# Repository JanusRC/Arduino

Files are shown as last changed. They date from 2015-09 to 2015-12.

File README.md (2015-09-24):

Janus Arduino Library
===

www.janus-rc.com

Janus Arduino repository for shield hardware and software references. 
The Janus Plugin Arduino Shield is fully compatible with the Arduino Uno and Leonardo currently.

This library should aid in getting a proof of concept with the Janus Plug in Modems done extremely 
quickly, allowing application development to focus on the bigger picture.

### Hardware
Arduino Shield and accessories - Designed in EAGLE 7.3.0

* `Plugin Shield v2.0`: Arduino Shield - Tested for the Uno/Leonardo
* `Eagle Library`: Janus Eagle Library

### Software
Janus software library for the Arduino platform, with example demos for standard M2M/IoT implementations.

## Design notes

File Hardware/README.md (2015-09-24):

Janus Arduino Library - Hardware
===

www.janus-rc.com

Janus Arduino hardware repository. Contains board designs for shields and accessories.

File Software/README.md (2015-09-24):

Janus Arduino Library - Software
===

www.janus-rc.com

Janus Arduino software repository. Contains backend library and demo code.

This library should aid in getting a proof of concept with the Janus Plug in Modems done extremely 
quickly, allowing application development to focus on the bigger picture.

These demos are for evaluations purposes only. Janus provides them as-is without any warranty or guarantees. 

### Janus Plugin Library
Arduino Shield library for use with the Janus Plugin Modem or Telit Modem.

* `Baudrate_Change`: Adjust the modem's baud rate.
* `Modem_Information`: Prints out the modem's information, including SIM serial and Network.
* `Modem_Terminal`: Cross connect the UART for quick evaluation and direct AT commands.
* `Modem_USBControl`: Turn the external USB on or off
* `SMS_Echo`: M2M Demo - Listens for incoming SMS, prints the information, and echoes back to the sender.
* `Socket_Dial`: M2M Demo - Dials out to a remote host, opens a serial bridge
* `Socket_Listen`: M2M Demo - Creates a listening host, once a client connects a serial bridge is open.

The Listener demo will create a completely open listener if you have an externally routable IP. Please be careful to shut this down
once testing is complete as you may find someone will connect to it and rack up your data usage. This is by default, but can be changed
in the demo by the user if needed with setupFirewall.

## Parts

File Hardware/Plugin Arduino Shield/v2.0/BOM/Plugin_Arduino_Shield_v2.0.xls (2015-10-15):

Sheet: Sheet1
Board Name | Plug in Module Arduino Shield
Item | Qty | Ref. Designator | Value | Part Number | Description | Package | Type | Side | Notes
0 | 6 | C1, C7, C8, C9, C10, C11 | 0.1uF | LMK105BJ104KV-F | CAP CER 0.1UF 10V 10% X5R 0402 | 402 | SMT | TOP
1 | 2 | C2, C3 | 10uF | JMK212BJ106KD-T | CAP CER 10UF 6.3V 10% X5R 0805 | 805 | SMT | TOP
2 | 2 | C4, C5 | .022uF | LMK105B7223KV-F | CAP CER 0.022UF 10V 10% X7R 0402 | 402 | SMT | TOP
3 | 1 | C6 | 100uF | GRM31CR60J107ME39K | CAP CER 100UF 6.3V 20% X5R 1206 | 1206 | SMT | TOP
4 | 1 | D1 | LED0603 | LG L29K-F2J1-24-Z | LED SMARTLED 570NM GREEN 0603 | 603 | SMT | TOP
5 | 1 | P5 | x | 10104110-0001LF | CONN RCPT STD MICRO USB TYPE B | MICRO USB SMT-RA | SMT | TOP
6 | 5 | Q1, Q2, Q3 | BJT-NPN | MMBT2222ALT1G | TRANS NPN 40V 0.6A SOT23 | SOT23 | SMT | TOP
7 | 1 | Q5 | MOSFET-P | IRLML6401TRPBF | MOSFET P-CH 12V 4.3A SOT-23 | SOT23 | SMT | TOP
8 | 2 | R1, R8 | 47k | ERJ-2RKF4702X | RES SMD 47K OHM 1% 1/10W 0402 | 402 | SMT | TOP
9 | 3 | R10, R11, R12 | 10k | ERJ-2RKF1002X | RES SMD 10K OHM 1% 1/10W 0402 | 402 | SMT | TOP
10 | 1 | R2 | 1.07k | ERJ-2RKF1071X | RES SMD 1.07K OHM 1% 1/10W 0402 | 402 | SMT | TOP
11 | 1 | R3 | 5.62k | ERJ-2RKF5621X | RES SMD 5.62K OHM 1% 1/10W 0402 | 402 | SMT | TOP
12 | 2 | R4, R5 | 2.2k | RC0402JR-072K2L | RES SMD 2.2K OHM 5% 1/16W 0402 | 402 | SMT | TOP
13 | 2 | R6, R7 | 4.7k | RC0402JR-074K7L | RES SMD 4.7K OHM 5% 1/16W 0402 | 402 | SMT | TOP
14 | 1 | R9 | 1.5k | RC0402JR-071K5L | RES SMD 1.5k OHM 5% 1/16W 0402 | 402 | SMT | TOP
15 | 1 | U1 | x | LMZ12002TZ-ADJ | IC BUCK SYNC ADJ 2A TO-PMOD-7 | TO-PMOD-7 | SMT | TOP
16 | 2 | U3, U4 | x | SN74LVC2T45DCT | IC BUS TRANSCVR 2BIT N-INV SM8 | 8-LSSOP | SMT | TOP
17 | 1 | P1 | x | M20-9720345 | 2x3 0.1” Header | 2x3 0.1” | Through Hole | TOP
18 | 1 | P2 | x | N/A | Wellshow SMA to GSC PCB R/A | RF SMA R/A 4 Pin | Through Hole | TOP
19 | 2 | P3, P4 | x | Arduino Header – 8 Pin | 8 Pin Long Lead Stacking Header | 1x8 0.1” | Through Hole | TOP
20 | 1 | P6 | x | Arduino Header – 6 Pin | 6 Pin Long Lead Stacking Header | 1x6 0.1” | Through Hole | TOP
21 | 1 | P7 | x | Arduino Header – 10 Pin | 10 Pin Long Lead Stacking Header | 1x10 0.1” | Through Hole | TOP
22 | 1 | P8 | x | SLW-124-01-G-S | 1x24 0.1” Samtec Low Profile Socket | 1x24 0.1” | Through Hole | TOP
23 | 1 | P9 | x | SLW-125-01-G-S | 1x25 0.1” Samtec Low Profile Socket | 1x25 0.1” | Through Hole | TOP
24 | 2 | S1, S2 | x | 1825027-5 | SWITCH TACTILE SPST-NO 0.05A 24V | 4 Pin THT | Through Hole | TOP
25 | 1 | U2 | x | HSPA910CF v1.0 | JANUS PLUG IN HSPA MODEM | x910 CF | Through Hole | TOP

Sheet: PuM_Arduino_Shield
Qty | Value | Device | Package | Parts | Description
1 | LED0603 |  | 603 | D1 | LEDs
5 | MOSFET-N |  | SOT23 | Q1, Q2, Q3, Q4, Q6 | IRLL014:
1 | MOSFET-P |  | SOT23 | Q5
2 | .022uF | C-0402 | 402 | C4, C5
2 | 0.1uF | C-0402 | 402 | C1, C7
1 | 1.07k | R-0402 | 402 | R2
1 | 1.5k | R-0402 | 402 | R9
5 | 100k | R-0402 | 402 | R1, R8, R10, R11, R12
1 | 100uF | C-1206 | 1206 | C6
2 | 10uF | C-0805 | 805 | C2, C3
2 | 2k | R-0402 | 402 | R4, R5
2 | 4.7k | R-0402 | 402 | R6, R7
1 | 5.62k | R-0402 | 402 | R3
1 | LMZ12002TZ-ADJ | TO-PMOD-7 | TO-PMOD-7 | U1
1 | RF_SMA | RF_SMA | RF SMA R/A 4 Pin | P2
2 | SWITCH-MOMENTARY | SWITCH-MOMENTARY | 4 Pin THT | S1, S2
1 | TERMINUS_X910CF | TERMINUS_X910CF | x910 CF | U2 | Terminus x910CF Plug in Module
1 | USB-MICROB | USB-MICROB | Micro USB SMT | P5 | Micro B USB Connector

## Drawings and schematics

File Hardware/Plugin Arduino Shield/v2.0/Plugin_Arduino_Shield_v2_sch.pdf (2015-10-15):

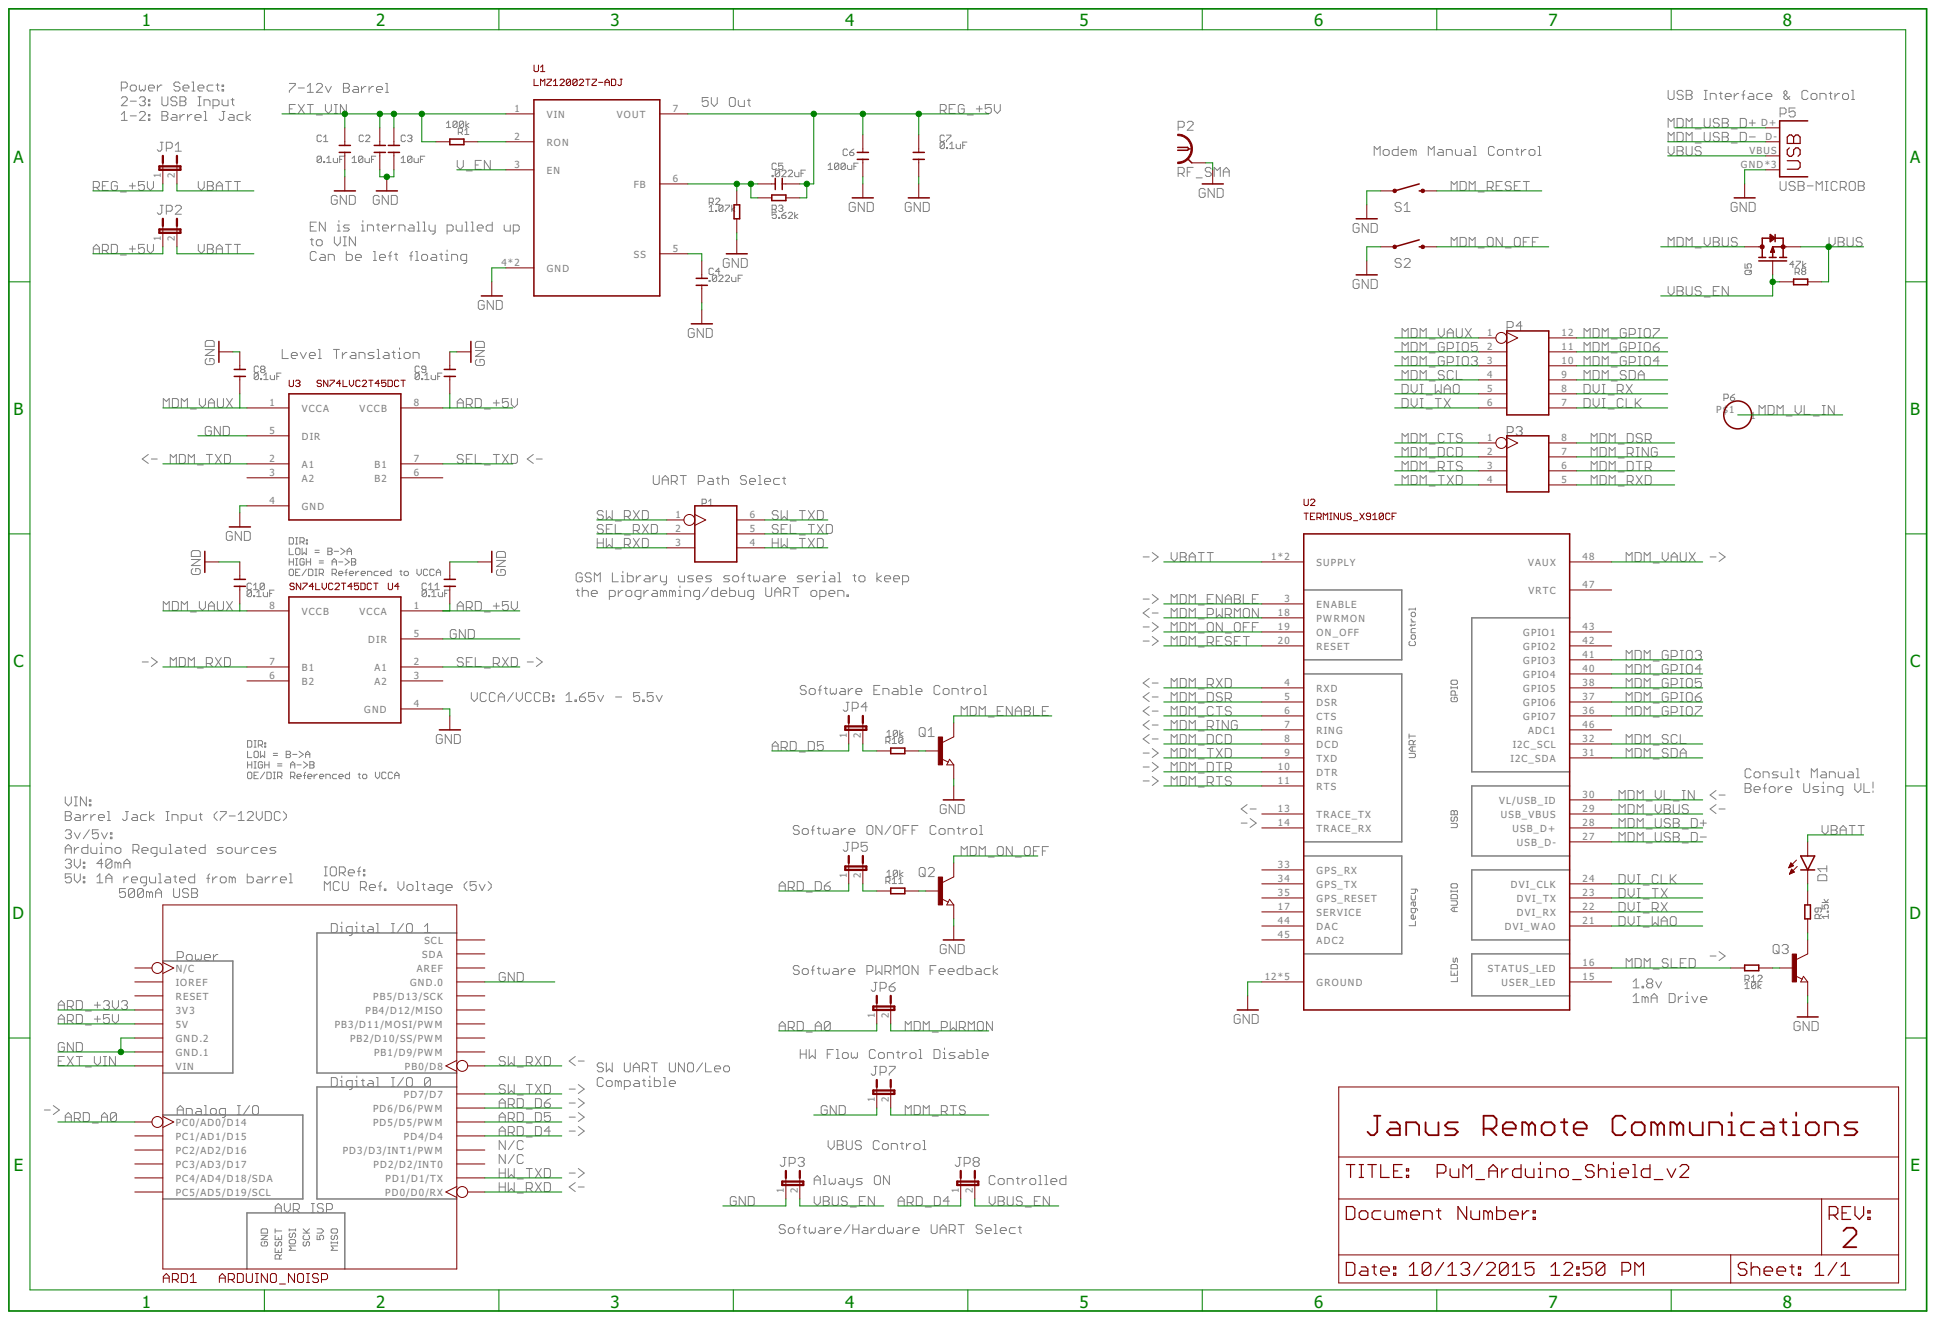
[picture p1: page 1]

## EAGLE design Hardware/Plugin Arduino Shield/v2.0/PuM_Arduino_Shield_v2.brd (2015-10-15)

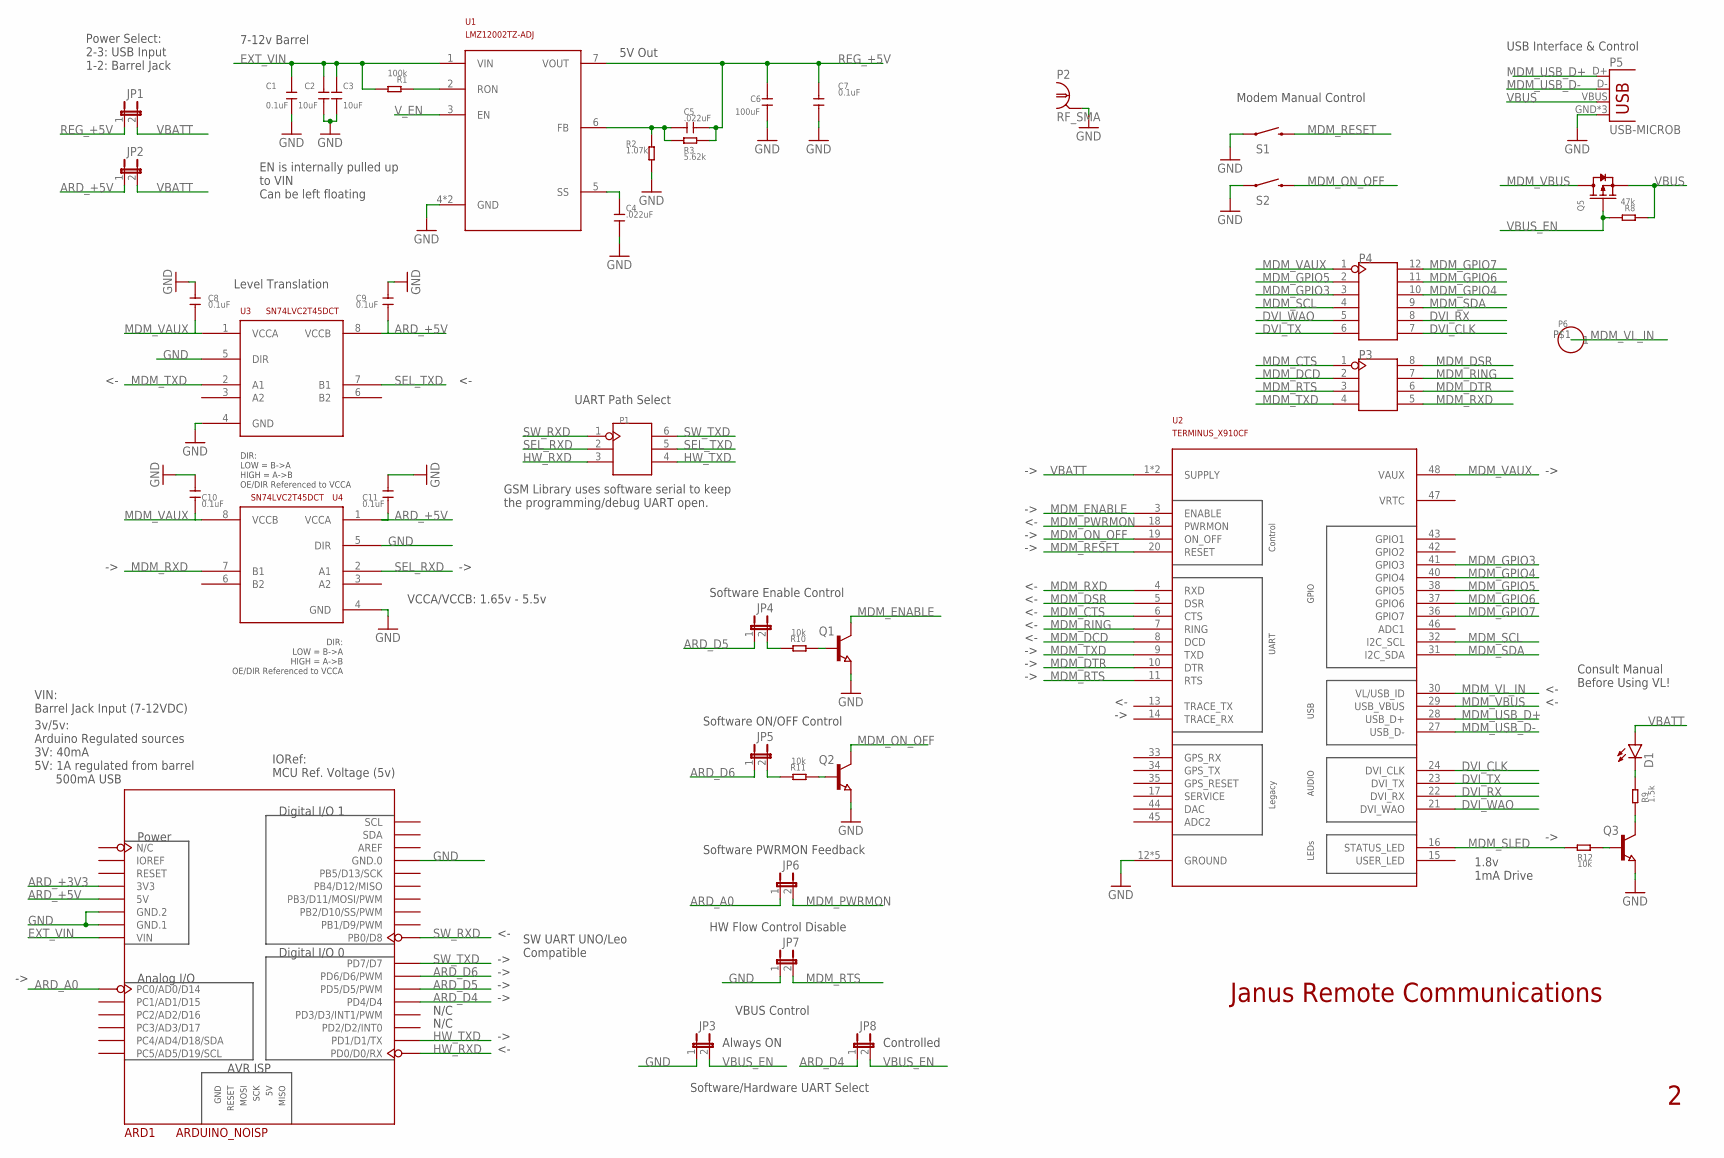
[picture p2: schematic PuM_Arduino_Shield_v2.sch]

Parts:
ARD1: ARDUINO_NOISP
C1, C7, C8, C9, C10, C11: 0.1uF; C0402
C2, C3: 10uF; C0805
C4, C5: .022uF; C0402
C6: 100uF; C1206
D1: LED0603; LED-0603
JP1, JP4, JP5, JP6, JP7, JP8: JUMPER-2SMD-NC; SJ_2S
JP2, JP3: JUMPER-2SMD-NO; SJ_2S-NO
P1: HEADER-2X3P-2.54; 2X3P-2.54
P2: RF_SMA; RF_SMA_NOPIN
P3: HEADER-2X4P-2.54; 2X4P-2.54
P4: HEADER-2X6P-2.54; 2X6P-2.54
P5: USB-MICROB
P6: HEADER-1P-35; 1P-65/35MIL
Q1, Q2, Q3: NPN-TRANSISTOR_SOT23; SOT23
Q5: MOSFET-P'SI2323CDS/SI2305DS<BR>'; SOT23
R1: 100k; R0402
R2: 1.07k; R0402
R3: 5.62k; R0402
R8: 47k; R0402
R9: 1.5k; R0402
R10, R11, R12: 10k; R0402
S1, S2: SWITCH-MOMENTARY-2SIDE_EZ; TACTILE-PTH-SIDEEZ
U1: LMZ12002TZ-ADJ; TO-PMOD-7
U2: TERMINUS_X910CF; X910CF
U3, U4: SN74LVC2T45DCT; LSSOP-8

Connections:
ARD_+3V3: ARD1.3V3
ARD_+5V: ARD1.5V, C9.1, C11.1, JP2.1, U3.8 (VCCB), U4.1 (VCCA)
ARD_A0: ARD1.A0 (PC0/AD0/D14), JP6.1
ARD_D4: ARD1.D4 (PD4/D4), JP8.1
ARD_D5: ARD1.D5 (PD5/D5/PWM), JP4.1
ARD_D6: ARD1.D6 (PD6/D6/PWM), JP5.1
DVI_CLK: P4.7, U2.24 (DVI_CLK)
DVI_RX: P4.8, U2.22 (DVI_RX)
DVI_TX: P4.6, U2.23 (DVI_TX)
DVI_WAO: P4.5, U2.21 (DVI_WAO)
EXT_VIN: ARD1.VIN, C1.2, C2.2, C3.2, R1.2, U1.1 (VIN)
GND: ARD1.GND0 (GND.0), ARD1.GND1 (GND.1), ARD1.GND2 (GND.2), C1.1, C2.1, C3.1, C4.1, C6.1, C7.1, C8.2, C9.2, C10.2, C11.2, JP3.1, JP7.1, P2.2, P2.3, P2.4, P2.5, P5.GND, P5.MT1 (GND), P5.MT2 (GND), Q1.2 (E), Q2.2 (E), Q3.2 (E), R2.2, S1.1, S2.1, U1.4 (GND), U1.EP (GND), U2.12 (GROUND), U2.25 (GROUND), U2.26 (GROUND), U2.39 (GROUND), U2.49 (GROUND), U3.4 (GND), U3.5 (DIR), U4.4 (GND), U4.5 (DIR)
HW_RXD: ARD1.D0 (PD0/D0/RX), P1.3
HW_TXD: ARD1.D1 (PD1/D1/TX), P1.4
MDM_CTS: P3.1, U2.6 (CTS)
MDM_DCD: P3.2, U2.8 (DCD)
MDM_DSR: P3.8, U2.5 (DSR)
MDM_DTR: P3.6, U2.10 (DTR)
MDM_ENABLE: Q1.3 (C), U2.3 (ENABLE)
MDM_GPIO3: P4.3, U2.41 (GPIO3)
MDM_GPIO4: P4.10, U2.40 (GPIO4)
MDM_GPIO5: P4.2, U2.38 (GPIO5)
MDM_GPIO6: P4.11, U2.37 (GPIO6)
MDM_GPIO7: P4.12, U2.36 (GPIO7)
MDM_ON_OFF: Q2.3 (C), S2.2, U2.19 (ON_OFF)
MDM_PWRMON: JP6.2, U2.18 (PWRMON)
MDM_RESET: S1.2, U2.20 (RESET)
MDM_RING: P3.7, U2.7 (RING)
MDM_RTS: JP7.2, P3.3, U2.11 (RTS)
MDM_RXD: P3.5, U2.4 (RXD), U4.7 (B1)
MDM_SCL: P4.4, U2.32 (I2C_SCL)
MDM_SDA: P4.9, U2.31 (I2C_SDA)
MDM_SLED: R12.2, U2.16 (STATUS_LED)
MDM_TXD: P3.4, U2.9 (TXD), U3.2 (A1)
MDM_USB_D+: P5.D+, U2.28 (USB_D+)
MDM_USB_D-: P5.D-, U2.27 (USB_D-)
MDM_VAUX: C8.1, C10.1, P4.1, U2.48 (VAUX), U3.1 (VCCA), U4.8 (VCCB)
MDM_VBUS: Q5.3 (D), U2.29 (USB_VBUS)
MDM_VL_IN: P6.P$1, U2.30 (VL/USB_ID)
unnamed: Q3.3 (C), R9.2
unnamed: JP5.2, R11.1
unnamed: R1.1, U1.2 (RON)
unnamed: C4.2, U1.5 (SS)
unnamed: C5.1, R2.1, R3.2, U1.6 (FB)
unnamed: D1.C, R9.1
unnamed: JP4.2, R10.1
unnamed: Q1.1 (B), R10.2
unnamed: Q2.1 (B), R11.2
unnamed: Q3.1 (B), R12.1
REG_+5V: C5.2, C6.2, C7.2, JP1.1, R3.1, U1.7 (VOUT)
SEL_RXD: P1.2, U4.2 (A1)
SEL_TXD: P1.5, U3.7 (B1)
SW_RXD: ARD1.D8 (PB0/D8), P1.1
SW_TXD: ARD1.D7 (PD7/D7), P1.6
VBATT: D1.A, JP1.2, JP2.2, U2.1 (SUPPLY), U2.2 (SUPPLY)
VBUS: P5.VBUS, Q5.2 (S), R8.2
VBUS_EN: JP3.2, JP8.2, Q5.1 (G), R8.1
V_EN: U1.3 (EN)

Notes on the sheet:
VIN: Barrel Jack Input (7-12VDC)
3v/5v: Arduino Regulated sources 3V: 40mA 5V: 1A regulated from barrel 500mA USB
IORef: MCU Ref. Voltage (5v)
GSM Library uses software serial to keep the programming/debug UART open.
EN is internally pulled up to VIN Can be left floating
7-12v Barrel
5V Out
Level Translation
Modem Manual Control
USB Interface & Control
Software ON/OFF Control
Software/Hardware UART Select
Software Enable Control
Software PWRMON Feedback
HW Flow Control Disable
Power Select: 2-3: USB Input 1-2: Barrel Jack
VBUS Control
Always ON
Controlled
N/C
SW UART UNO/Leo Compatible
Consult Manual Before Using VL!
1.8v 1mA Drive
UART Path Select
VCCA/VCCB: 1.65v - 5.5v
Janus Remote Communications

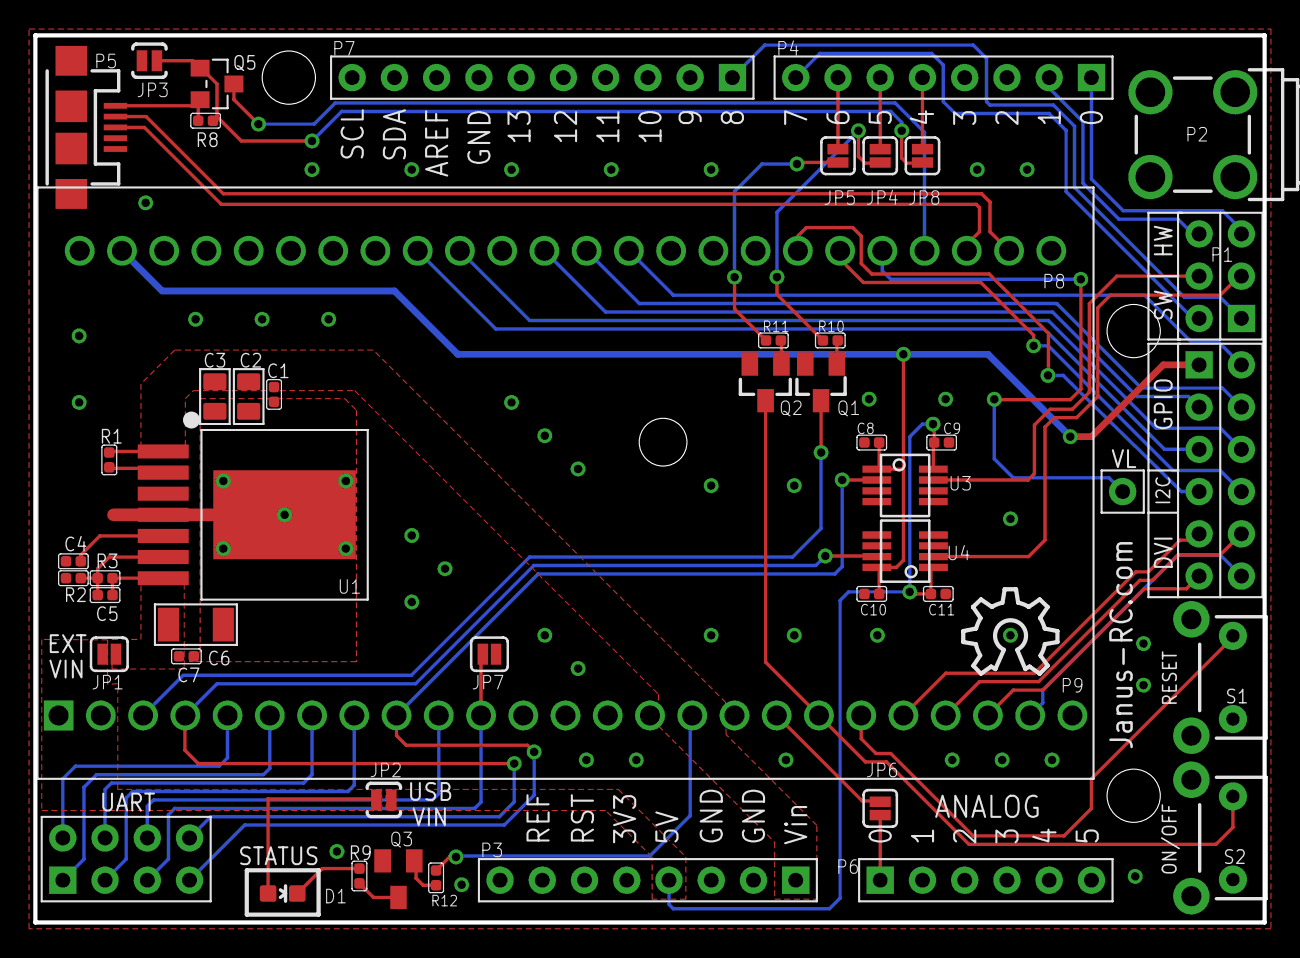
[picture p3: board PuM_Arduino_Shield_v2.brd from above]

Board: 2 copper layers, 73.9 x 53.3 mm, 47 parts (0 on the bottom side), 56 nets.

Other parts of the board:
DRILEGEND: DRILEGEND
U$2: OSHW_10X200_NOTEXT

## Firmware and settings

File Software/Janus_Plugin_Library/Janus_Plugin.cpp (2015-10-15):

/***************************************************
  This is a library for the Janus plug in modem arduino shield

  The hardware & IO control are designed to work with the
  DIP package Terminus Plug in Modem
  http://www.janus-rc.com/terminuscf.html

  Required HW: 2 Pins = TX, RX, ON_OFF (else you need external button)
  Optional HW: 3 Pins = ENABLE, VBUS ENABLE, PWRMON

  The AT command control and higher level functions are usable
  with most Telit modems, however.

  Written by Clayton Knight, cknight@janus-rc.com
  Heavy reference from the Adafruit Fona Library
  BSD license, all text above must be included in any redistribution
 ****************************************************/
#include <avr/pgmspace.h>
    // next line per http://postwarrior.com/arduino-ethershield-error-prog_char-does-not-name-a-type/
#define prog_char  char PROGMEM

#if (ARDUINO >= 100)
  #include "Arduino.h"
  #ifndef __SAM3X8E__  // Arduino Due doesn't support SoftwareSerial
    #include <SoftwareSerial.h>
  #endif
#else
  #include "WProgram.h"
  #include <NewSoftSerial.h>
#endif

#include "Janus_Plugin.h"

//Create object
Janus_Plugin::Janus_Plugin(int8_t enable, int8_t onoff, int8_t vbusenable, int8_t pwrmon)
{
  _enablepin = enable;
  _onoffpin = onoff;
  _vbusenpin = vbusenable;
  _pwrmonpin = pwrmon;
  
  _modem = HE910;	//placeholder for eventual modem class usage.

  ModemSerial = 0;
}

//Starting function
//Initializes the I/O correctly, we leave higher level control to the user
//This is because they may want to automatically start it, or control the I/O differently.
boolean Janus_Plugin::begin(Stream &port) {
  ModemSerial = &port;

  //Set the I/O
  pinMode(_enablepin, OUTPUT);
  pinMode(_onoffpin, OUTPUT);
  pinMode(_vbusenpin, INPUT);  	//OC Configuration. Off by default
  pinMode(_pwrmonpin, INPUT);   //ADC Usage

  return true;
}

/***************************************************************
 HIGH LEVEL
***************************************************************/

/*********************************
Modem low level control functions
*********************************/
void Janus_Plugin::turnOnOff(int OnPin, int inDelay)
{ 
  digitalWrite(OnPin, HIGH);
  delay(inDelay);
  digitalWrite(OnPin, LOW);
}

boolean Janus_Plugin::vbus_ON(int VBUSPin)
{
	//Open collector control
	pinMode (VBUSPin, OUTPUT) ; // drive pin low, turn ON
return true;
}

boolean Janus_Plugin::vbus_OFF(int VBUSPin)
{
	//Open collector control
	pinMode (VBUSPin, INPUT) ;  // hi-Z state, turn OFF
return false;
}

void Janus_Plugin::enable(int ENPin)
{
  digitalWrite(ENPin, LOW);
}

void Janus_Plugin::disable(int ENPin)
{
  digitalWrite(ENPin, HIGH);
}

//Function to check the PWRMON feedback from the modem
//Arguments: Analog power pin, threshold voltage
uint8_t Janus_Plugin::isModemON(int PWRPin, int inThresh)
{
  int readPWRMON = 0; //PWRMON read value container

  readPWRMON = analogRead(PWRPin);  //Read PWRMON

  // Convert the analog reading (which goes from 0 - 1023) to a voltage (0 - 5V):
  float voltage = readPWRMON * (5.0 / 1023.0);

  if (voltage > inThresh)
    return 1;
  else
    return 0;
}

/*********************************
Modem higher level control functions
*********************************/
uint8_t Janus_Plugin::setBaudrate(uint32_t baud)
{
  uint8_t Fault = FAULT_OK;  //Initialize Fault
  char sndstring[15];    	 //Temporary buffer AT+IPR=115200\r\n

  //Format and store the full string to the temp buffer
  sprintf(sndstring,"AT+IPR=%lu",baud); 
    
  //Send the Query
  Fault = sendAT(sndstring, ATC_STD_TIMEOUT);

return Fault;
}

//***************************

uint8_t Janus_Plugin::getSerialNumber(char *outString)
{
  uint8_t Fault = FAULT_OK;  //Initialize Fault
  char string[30];       	 //buffer
  uint8_t i = 0;

  memset(string,0,sizeof(string));
    
  //Send the Query
  Fault = sendATStr(F("AT+CGSN"), string, ATC_STD_TIMEOUT);

  // 357164040646914
  while(string[i] != '\r')
  {
	*outString = string[i];
	*outString++;
	i++;
  }
	
return Fault;
}

//***************************

uint8_t Janus_Plugin::getMake(char *outString)
{
  uint8_t Fault = FAULT_OK;  //Initialize Fault
  char string[30];       	 //buffer
  uint8_t i = 0;

  memset(string,0,sizeof(string));
    
  //Send the Query
  Fault = sendATStr(F("AT+CGMI"), string, ATC_STD_TIMEOUT);

  // Telit
  while(string[i] != '\r')
  {
	*outString = string[i];
	*outString++;
	i++;
  }

return Fault;
}

//***************************

uint8_t Janus_Plugin::getModel(char *outString)
{
  uint8_t Fault = FAULT_OK;  //Initialize Fault
  char string[30];       	 //buffer
  uint8_t i = 0;

  memset(string,0,sizeof(string));
    
  //Send the Query
  Fault = sendATStr(F("AT+CGMM"), string, ATC_STD_TIMEOUT);

  // GE865-QUAD
  while(string[i] != '\r')
  {
	*outString = string[i];
	*outString++;
	i++;
  }

return Fault;
}

//***************************

uint8_t Janus_Plugin::getFirmware(char *outString)
{
  uint8_t Fault = FAULT_OK;  //Initialize Fault
  char string[30];       	 //buffer
  uint8_t i = 0;

  memset(string,0,sizeof(string));
    
  //Send the Query
  Fault = sendATStr(F("AT+CGMR"), string, ATC_STD_TIMEOUT);

  // 12.00.006
  while(string[i] != '\r')
  {
	*outString = string[i];
	*outString++;
	i++;
  }

return Fault;
}

//***************************

uint8_t Janus_Plugin::waitForSIMReady(int Timeout, boolean *SIMStatus)
{
    uint8_t Fault = FAULT_OK;   //Initialize Fault State
    char string[20];           //Temp buffer
    int ScaledTimeout = Timeout/1000;  //Scale the timeout to more of a 'tries' type

    memset(string,0,sizeof(string));
  
    *SIMStatus = false;  //Initialize the variable
  
    while(ScaledTimeout >= 0)
    {
      ScaledTimeout--;
      
      Fault = sendATStr(F("AT+CPIN?"), string, ATC_STD_TIMEOUT);
      if (!Fault)
      {
        // +CPIN: READY
        if (strncmp(string,"+CPIN: READY",12) == 0) 
        {
          *SIMStatus = true;  //Update variable
          return Fault;
        }    
        //TODO - Add extra faults to handle things like needing a PIN
      }
      delay(1000); //Delay a second to avoid hammering the SIM
    }

//SIM not ready, return a timeout
return FAULT_TIMEOUT;
}

//***************************

uint8_t Janus_Plugin::getSIMSerial(char *outString)
{
  uint8_t Fault = FAULT_OK;  //Initialize Fault
  char string[30];      //buffer

  memset(string,0,sizeof(string));
    
  //Send the Query
  Fault = sendATStr(F("AT#CIMI"), string, ATC_STD_TIMEOUT);

  // #CIMI: 310260584850247
  if (strncmp(string,"#CIMI: ",7) == 0) 
    strncpy(outString,&string[7], 15);

return Fault;
}

//***************************
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

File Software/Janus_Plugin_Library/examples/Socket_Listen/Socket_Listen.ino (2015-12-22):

/***************************************************
  This is an example for the Janus Plug in Modem arduino library

  The hardware & IO control are designed to work with the
  DIP package Terminus Plug in Modem
  http://www.janus-rc.com/terminuscf.html

  Required HW: 2 Pins = TX, RX, ON_OFF (else you need external button)
  Optional HW: 3 Pins = ENABLE, VBUS ENABLE, PWRMON

  The AT command control and higher level functions are usable
  with most Telit modems, however.

  Written by Clayton Knight, cknight@janus-rc.com
  Heavy reference from the Adafruit Fona Library
  BSD license, all text above must be included in any redistribution
 ****************************************************/

/*************
Socket Listen Demo
This demo configures the modem to listen for an incoming connection. Currently it only handles 1 client.
Once the socket has been opened it creates a basic serial bridge and passes data in 64B packets.

The bridge is done via command mode, allowing AT command access during the bridge
This is useful if you want to send AT response data to this host (RSSI, etc.)

It's a little slower, but for this platform it allows the most flexibility. 
Using data/online mode can be done with some minor edits to the bridge loop, but remember
that this utilizes software serial at a lower rate, so if speed is a requirement you MUST
adjust this to use hardware serial. Don't expect blazing speeds from online mode without it.
 
Telit modems by default run 115200, and we bring it down
to 19200 since the sofware serial is far too slow to catch the higher rate.

Please see the baud rate example if you haven't set the modem's baud rate yet.

REQUIRED - Uncomment USE_SOCKET in Janus_Plugin.h
REQUIRED - Edit the GPRS information for your APN and host server.
************/

#include <Janus_Plugin.h>

/***************
User defines for the shield/Arduino
***************/
//Basic Arduino pins
#define LEDPIN 13

//UART
#define MDM_SW_TXD 7
#define MDM_SW_RXD 8

//Modem Hardware Control
#define MDM_ENABLE 5      //Regulator enable, active drive thru FET switch
#define MDM_ON_OFF 6      //Modem ON/OFF toggle pin, active drive thru FET switch
#define MDM_VBUS_EN 4     //Set as OC, drop low to enable VBUS via FET load switch
#define MDM_PWRMON A0     //Power monitor feedback signal. ADC Channel 0, Digital pin 14

//Misc.
#define ONOFF_DELAY 3000  //On Off Pulse time, General use = 3s. Adjust to specific modem timing if required.

//Application defines
#define BAUDRATE 19200    //New, lower baud rate that's useful for our library and SWSerial
#define COMMANDMODE 1     //Socket type, command
#define DATAMODE 0        //Socket type, online/data

/***************
Library Implementations
***************/
// This is to handle the absence of software serial on platforms
// like the Arduino Due. Modify this code if you are using different
// hardware serial port, or if you are using a non-avr platform
// that supports software serial.
#ifdef __AVR__
#include <SoftwareSerial.h>
SoftwareSerial ModemSS(MDM_SW_RXD, MDM_SW_TXD); // RX, TX
SoftwareSerial *ModemSerial = &ModemSS;         //Create pointer to the address
#else
HardwareSerial *ModemSerial = &Serial1;         //Use HW Serial when required
#endif

//Instance the modem constructor
Janus_Plugin myModem = Janus_Plugin(MDM_ENABLE, MDM_ON_OFF, MDM_VBUS_EN, MDM_PWRMON);

//**********************************
//**********************************

void setup() {
  Serial.begin(BAUDRATE);       //Start debug output at 19200
  ModemSerial->begin(BAUDRATE); //Start the serial interface to the modem, just access thru the pointer
  myModem.begin(*ModemSerial);  //Pass in the pointer-to-address and start the library
  
  Serial.println(F("Plug in Terminus Socket Listen Demo"));

  //Initial check
  //Not on, turn everything on, check against threshold voltage (2v)
  if (myModem.isModemON(MDM_PWRMON, 2) == 0)
  { 
    myModem.enable(MDM_ENABLE);   //Ensure the modem is enabled
    delay(200);                   //Delay 200ms for regulator to stabilize
    
    Serial.println(F("Modem OFF, turning ON"));
    myModem.turnOnOff(MDM_ON_OFF, ONOFF_DELAY); //Built in pulse w/ delay
  }

  Serial.println(F("Modem ON"));
  delay(5000);  //Let the modem warm up, 5s is more than enough

  myModem.sendAT(F("ATE0"), ATC_STD_TIMEOUT);       //Disable echo
  myModem.sendAT(F("AT+CMEE=2"), ATC_STD_TIMEOUT);  //Turn on verbose
}

void loop() {
  /***************
  Application variables
  ***************/
  uint8_t Fault = FAULT_OK;         //Initialize Fault State.
  boolean ModemSIMReady = false;    //Initial state, SIM status
  uint8_t NetworkCellRegState = 0;  //Initial state, network registration status
  uint8_t NetworkDataRegState = 0;  //Initial state, network registration status

  //GPRS
  boolean NetworkActivationState;  //Context Activation: 0 = Not Active, 1 = Active
  char NetworkIP[20];              //Ex: 255.255.255.255
  uint8_t ConnID = 1;              //Socket Connection ID - Only 1 client is handled
  boolean SocketOpen = false;      //Connection status
  char SocketReceiveBuf[64];       //Socket command mode receive buffer
  char SocketSendBuf[64];          //Socket command mode sending buffer
  int i;                           //Counter
  char *res;
  
  //Context Information - REQUIRED TO UPDATE THIS
  char AccessPointName[] = "yourapn"; //Ex: i2gold, internet, proxy
  char UserName[] = "";
  char Password[] = "";
  
  //Socket Information - REQUIRED TO UPDATE THIS
  char LocalPort[] = "yourport";      //Ex: 80

  /***************
  Application Begin
  ***************/
  //Loop this for continual checks/on time
  while(1)
  {
    //Adjust this if not using a SIM based module (maybe check the modem type firt)
    ModemSIMReady = false;
    Fault = myModem.waitForSIMReady(NET_QRY_TIMEOUT, &ModemSIMReady);
  
    if (!Fault) Serial.println(F("SIM Ready"));
  
    //Adjust this if not using a SIM based module (maybe check the modem type firt)
    if (ModemSIMReady)
    {  
      //*****************************
      // Registration Checks
      //*****************************
      Serial.println(F("Waiting for registration"));
      NetworkCellRegState = 0;
      //Check cellular against defined HOME/ROAMING states
      while (NetworkCellRegState != HOME && NetworkCellRegState != ROAMING)
      {
        Fault = myModem.getRegStatus(&NetworkCellRegState);
        delay(500); //Delay half second to avoid hammering the interface
      }

      //Check data against defined HOME/ROAMING states
      NetworkDataRegState = 0;
      while (NetworkDataRegState != HOME && NetworkDataRegState != ROAMING)
      {
        Fault = myModem.getDataStatus(&NetworkDataRegState);
        delay(500); //Delay half second to avoid hammering the interface
      }

      //*****************************
      // Context Activation
      //*****************************
      Serial.println(F("Registered, Activating Context"));
      Fault = myModem.setupContext(AccessPointName);
      
      //Check if we already have a context up
      if (!Fault) Fault = myModem.getContext(NetworkIP, &NetworkActivationState);

      //If not, activate it
      if (!NetworkActivationState)
        Fault = myModem.activateContext(UserName, Password, NetworkActivationState);
      
      if (!Fault)
      {
        //Update the context information for display/use
        Fault = myModem.getContext(NetworkIP, &NetworkActivationState);
        Serial.print(F("Activation State:  ")); Serial.println(NetworkActivationState, DEC);
        Serial.print(F("Context IP:        ")); Serial.println(NetworkIP); 
      }

      //*****************************
      // Socket/GPRS Handling
      //*****************************
      //Setup the socket information for SID #1
      Fault = myModem.socketSetup(1);

      Serial.println(F("Closing previous socket instances")); 
      //Ensure the socket is closed by the modem.
      Fault = myModem.socketClose(ConnID);  

      Fault = myModem.setupFirewall("0.0.0.0", "0.0.0.0");
      if (!Fault) Fault = myModem.socketListen(1, LocalPort);

      Serial.print(F("Listener open on: "));
      Serial.print(NetworkIP); Serial.print(F(":")); Serial.println(LocalPort); 

      //Flush the UARTs
      Serial.println(F("Flushing UARTs."));
      while (Serial.available() || myModem.available())
      {
        myModem.read();   //Flush the RX
        Serial.read();    //Flush the RX
      }

      //*****************************
      // Client connection handling
      //*****************************
      Serial.println(F("Ready, Waiting for Client..."));
      SocketOpen = false; //Initialize at the beginning
      //Wait for the SRING
      while (SocketOpen == false)
      {
        //Read the AT interface
        res = NULL; //reset res
        res = myModem.parseLine();  //Grab the raw line data
        
        //Buffer is not null, we found something
        if (res)
        {
          //Fast reference to a fault code
          Fault = myModem.modemToFaultCode(res);

          //Check for incoming SRING via the standard fault code handler
          // SRING: x. 
          if (Fault == FAULT_SRING)
          {
            Fault = myModem.socketAccept(ConnID); //Accept the incoming connection
            if (Fault == FAULT_CONNECT)           //Look for the CONNECT
              Fault = myModem.enterCMDMode();     //Drop to command mode
              
            if (!Fault) 
            {
              SocketOpen = true;                  //Mark the socket as open
              Serial.println(F("Client Connected."));
            }
            break;
          } 

          // NO CARRIER - Server has closed the connection or we lost the network.
          if (Fault == FAULT_NO_CARRIER)
          {
            Serial.println(F("Listener Closed - Network Terminated."));
            break;
          }
          // ELSE - An error or odd failure, either way exit and check everything again.
          if (Fault == FAULT_ERROR)
          {
            Serial.println(F("Listener Closed - Error."));
            break;
          }
        }
      } //Whileend
      
      //*****************************
      // Data Forwarding/Bridge
      //*****************************
      while(SocketOpen == true)
      {  
        //****************** 
        // Socket Receive
        //****************** 
        //Read the AT interface
        res = NULL; //reset res
        res = myModem.parseLine();  //Grab the raw line data
        
        //Buffer is not null, we found something
        if (res)
        {
          //Fast reference to a fault code
          Fault = myModem.modemToFaultCode(res);

          //Check for incoming expected message types, then handle accordingly
          // SRING: x - Valid Data
          if (Fault == FAULT_SRING)
          {
            //Grab 64 bytes (max of 255) from the buffer
            memset(SocketReceiveBuf,0,sizeof(SocketReceiveBuf));
            Fault = myModem.socketReceive(ConnID, 64, SocketReceiveBuf);
  
            if (!Fault) Serial.print(F("Received data: ")); Serial.println(SocketReceiveBuf);
          }

          // NO CARRIER - Server has closed the connection or we lost the network.
          if (Fault == FAULT_NO_CARRIER)
          {
            Serial.println(F("Socket Closed."));
            SocketOpen = false;  //Mark the socket closed
            break;
          }
          // ELSE - An error or odd failure, either way exit and check everything again.
          if (Fault == FAULT_ERROR)
          {
            Serial.println(F("Socket Closed - Error."));
            SocketOpen = false;  //Mark the socket closed
            break;
          }
        }

        i = 0;
        //****************** 
        // Socket Send
        //****************** 
        while (Serial.available()) 
        {
          //Aggregate the serial data
          SocketSendBuf[i] = Serial.read();
          i++;
          delay(1); //Small delay to catch the full string/data entered.
        }

        if (i > 0)
        {
          //Send the buffered data out
          Fault = myModem.socketSend(ConnID, SocketSendBuf);
          if (!Fault) Serial.print(F("Sent data: ")); Serial.println(SocketSendBuf);
          memset(SocketSendBuf,0,sizeof(SocketSendBuf));  //clear buffer
          i = 0;  //Reset the counter
        }
      }//whileend2

      Serial.println(F("10s Before Retry."));
      delay(10000);   //Delay 10 seconds before trying the connection/loop again
    }//SIMcheckend
  }//whileend1

}//Mainend

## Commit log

2015-09-24 Janus Arduino Library
    [Plugin_Arduino_Shield_v2.0.xls, PuM_Arduino_Shield_v2.brd, PuM_Arduino_Shield_v2.sch]
2015-10-15 Updated board design and library
    [Plugin_Arduino_Shield_v2.0.xls, PuM_Arduino_Shield_v2.brd, PuM_Arduino_Shield_v2.sch]
2015-12-22 Update Baudrate_Change.ino
    Change pin #defines & fix baud rate
    [Baudrate_Change.ino]
2015-12-22 Update Modem_Information.ino
    Change pin #defines
2015-12-22 Update Modem_Terminal.ino
    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
2015-12-22 Update Modem_USBControl.ino
    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
2015-12-22 Update SMS_Echo.ino
    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
2015-12-22 Update Socket_Dial.ino
    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
2015-12-22 Update Socket_Listen.ino
    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
2016-05-18 Remote_Control_Using_SMS_Commands
    This arduino program allows you to control the devices (LED, Buzzer, LCD) attached to Arduino GPIO pins using commands sent through an SMS.
    [Remote_Control_Using_SMS_Commands.ino]

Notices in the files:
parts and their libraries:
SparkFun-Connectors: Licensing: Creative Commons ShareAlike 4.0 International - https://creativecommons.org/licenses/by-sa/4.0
